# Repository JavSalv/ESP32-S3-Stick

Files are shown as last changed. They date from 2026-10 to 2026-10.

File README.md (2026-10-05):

# ESP32-S3 Stick

> Breadboard-friendly ESP32-S3 module with onboard RTC, LiPo battery charger, and USB-C — designed for low-power and deep-sleep applications.

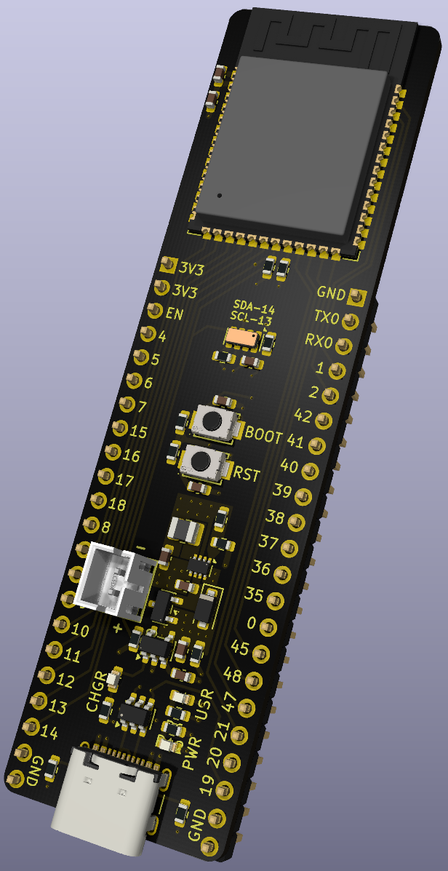
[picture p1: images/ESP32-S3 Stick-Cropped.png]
Board render


---

## Overview

The ESP32-S3 Stick is a compact development module built around the **ESP32-S3-WROOM-1** that fits standard 830-point breadboards leaving room on both sides of the module.
It combines a complete power path (USB-C input, LiPo charging, and a synchronous buck converter) with an ultra-low-power RTC clock, making it well suited for prototyping battery-operated IoT nodes, data loggers, and any application that relies on deep sleep.

---

## Features

### Microcontroller
- **ESP32-S3-WROOM-1-N16R2**: Dual-core Xtensa LX7 @ up to 240 MHz, 16 MB Flash, 2 MB PSRAM
- All GPIOs broken out to the standard 22-pin headers.

### Power
- **USB-C input** (USB 2.0, 16-pin receptacle) with correct CC pull-downs for UFP/sink detection
- **MCP73831** single-cell LiPo/Li-Ion charger with 100 mA charge current (configurable via R_PROG)
- **TPS629210** synchronous buck converter for 3.3V output up to 1A.
- **P-channel MOSFET load-sharing** (DMP2045U-7) seamless switchover between USB and battery with low dropout penalty.
- **USBLC6-2SC6** TVS diode array for USB ESD protection.

### RTC
- **RV-3028-C7** — ultra-low-power RTC (40 nA), ±1 ppm accuracy, I²C interface on IO13 (SCL) / IO14 (SDA)

### Connectivity & I/O
- **USB-C** - USB 2.0 FS data lines connected directly to ESP32-S3 USB transceiver (USB_D+ / USB_D−)
- **UART0** (TXD0 / RXD0) broken out for programming and debug
- **2 × 22-pin headers** 2.54 mm pitch, breadboard-compatible

### User Interface
- **RST button**: Reset the controller
- **BOOT button**: Enters download mode when held during reset
- **3 × status LEDs**: Charge status, power status and one user LED connected to GPIO48

---

## Pin Map

The Pin Map is similar to other ESP32-S3 modules like the ESP32-S3-DevKitC-1 or cheaper AliExpress clones.

ESP32-S3-DevKitC-1 Pinout

> **Note:** IO0 is the BOOT strapping pin — avoid driving it LOW at power-on unless entering download mode. IO45 and IO46 are also strapping pins; check the ESP32-S3 datasheet before using them as outputs.

### LiPo Battery

Connect a single-cell LiPo or Li-Ion battery (3.7 V nominal) to the battery connector (JST PH 2-pin 2mm pitch connector). The MCP73831 charges the battery at 100mA.

## License

Hardware design files are open source. See [LICENSE](LICENSE) for details.

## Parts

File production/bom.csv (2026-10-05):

Designator | Footprint | Quantity | Value | LCSC Part #
BT1 | CONN-TH_B2B-PH-K-S | 1 | JST Battery connector | C131337
C1, C9 | 0603 | 2 | 22uF
C2, C3, C4, C7 | 0603 | 4 | 0.1uF
C5, C6, C8 | 0603 | 3 | 4.7uF
D1, D2, D3 | 0603 | 3 | LED_R
D4 | D_SOD-123F | 1 | SS24
J1 | USB_C_Receptacle_GCT_USB4105-xx-A_16P_TopMnt_Horizontal | 1 | USB_C_Receptacle_USB2.0_16P
J2, J3 | PinHeader_1x22_P2.54mm_Vertical | 2 | Header 22pin
L1 | 1008 | 1 | 2.2uH
Q1 | SOT-23 | 1 | DMP2045U-7
R1, R10, R11, R4, R7, R8, R9 | 0603 | 7 | 10K
R12, R2, R3, R5, R6 | 0603 | 5 | 5.1K
R13 | 0603 | 1 | 100K
R14 | 0603 | 1 | 619K/0.1%
R15 | 0603 | 1 | 137K/0.1%
SW1, SW2 | SW-SMD_L3.9-W3.0-P4.45 | 2 | Tactile SW | C115357
U1 | ESP32-S3-WROOM-1 | 1 | ESP32-S3-WROOM-1
U2 | SOT-23-6 | 1 | USBLC6-2SC6
U3 | SOT-23-5 | 1 | MCP73831-2-OT
U4 | MicroCrystal_C7_SON-8_1.5x3.2mm_P0.9mm | 1 | RV-3028-C7
U5 | SOT-583-8 | 1 | TPS629210

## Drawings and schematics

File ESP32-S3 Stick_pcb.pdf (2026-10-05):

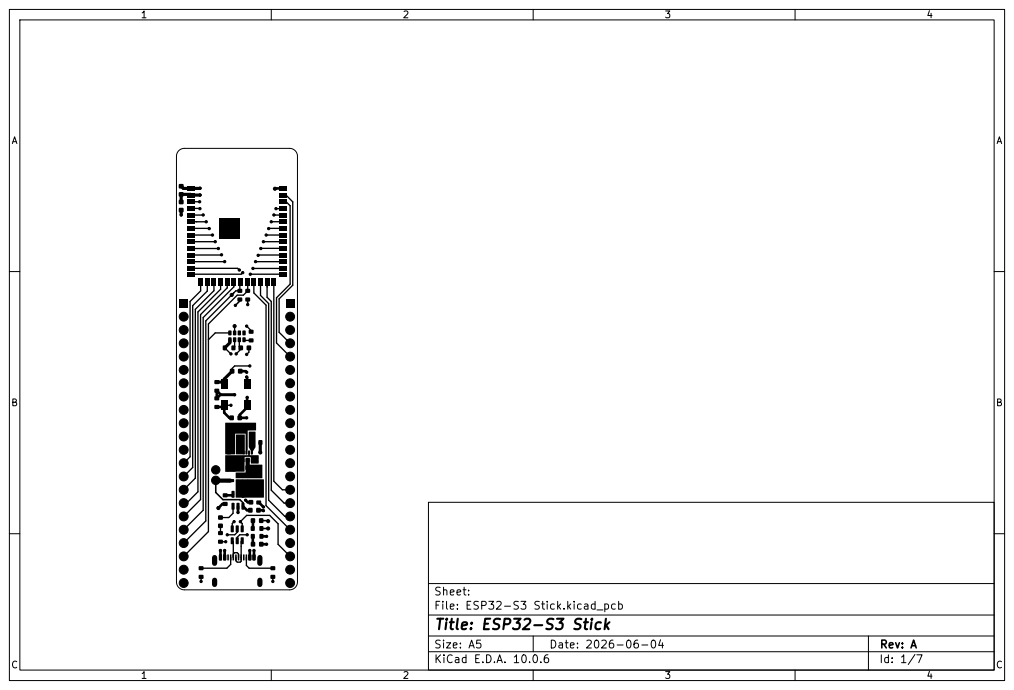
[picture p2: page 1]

Size: A5 | Rev: A | C Date: 2026-06-04
KiCad E.D.A. 10.0.6 | Id: 1/7

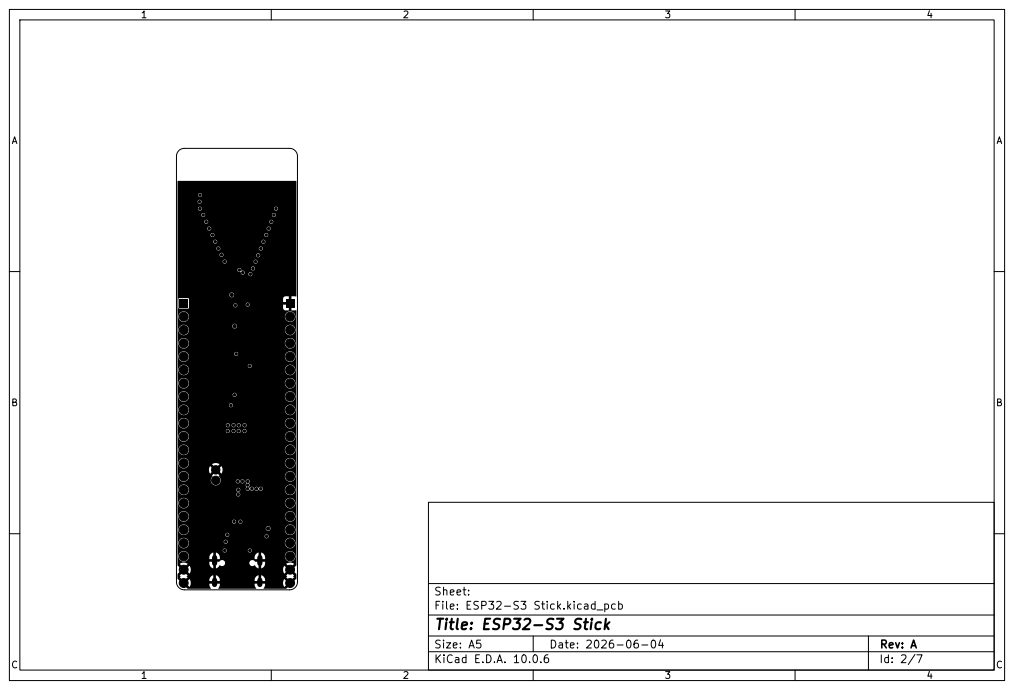
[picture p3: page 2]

Size: A5 | Rev: A | C Date: 2026-06-04
KiCad E.D.A. 10.0.6 | Id: 2/7

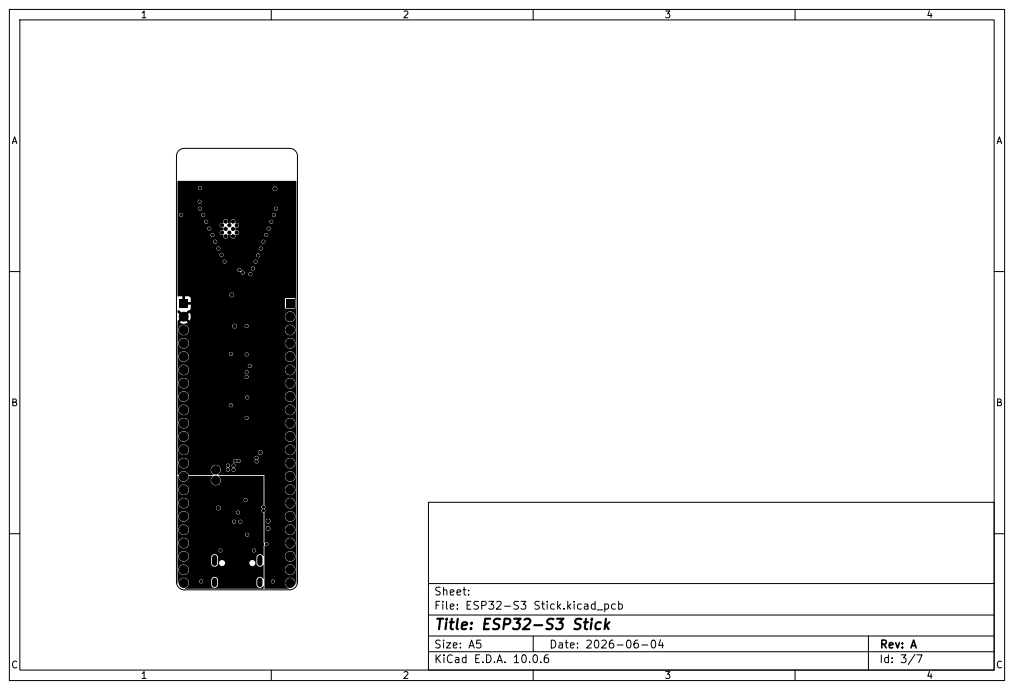
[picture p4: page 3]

Size: A5 | Rev: A | C Date: 2026-06-04
KiCad E.D.A. 10.0.6 | Id: 3/7

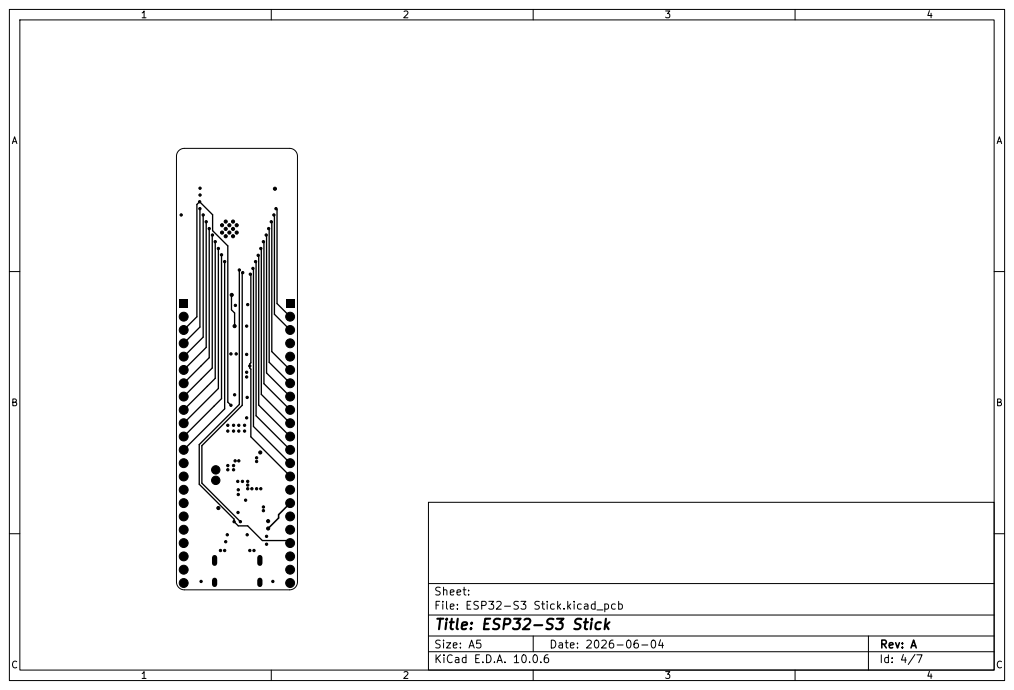
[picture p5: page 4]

Size: A5 | Rev: A | C Date: 2026-06-04
KiCad E.D.A. 10.0.6 | Id: 4/7

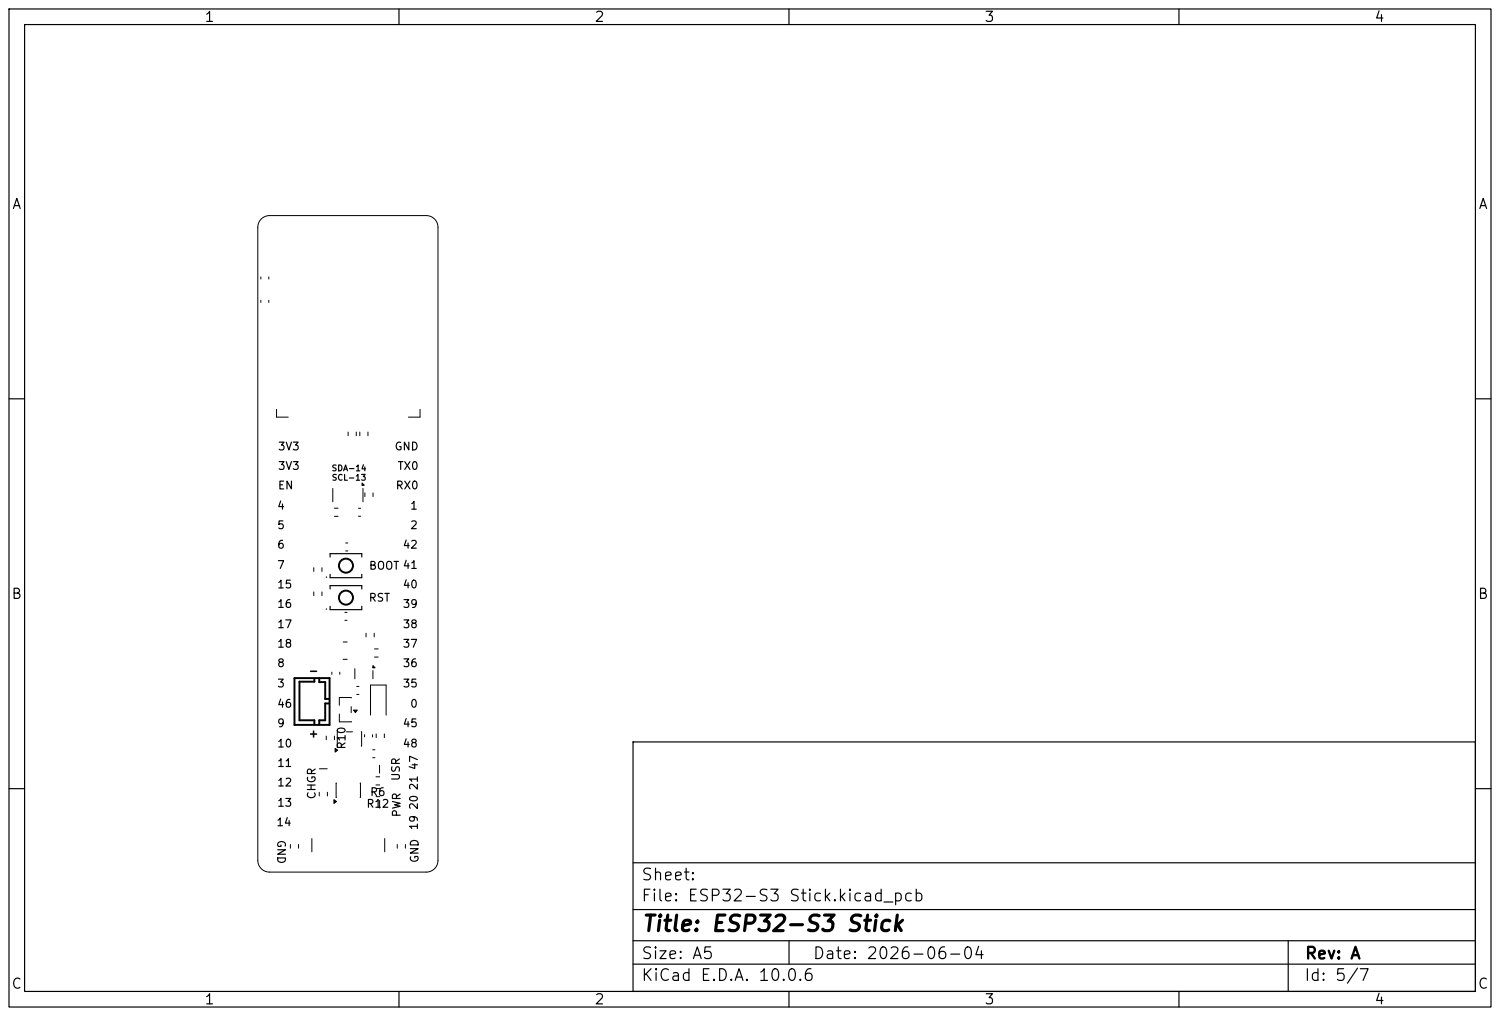
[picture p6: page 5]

Size: A5 | Rev: A | C Date: 2026-06-04
KiCad E.D.A. 10.0.6 | Id: 5/7

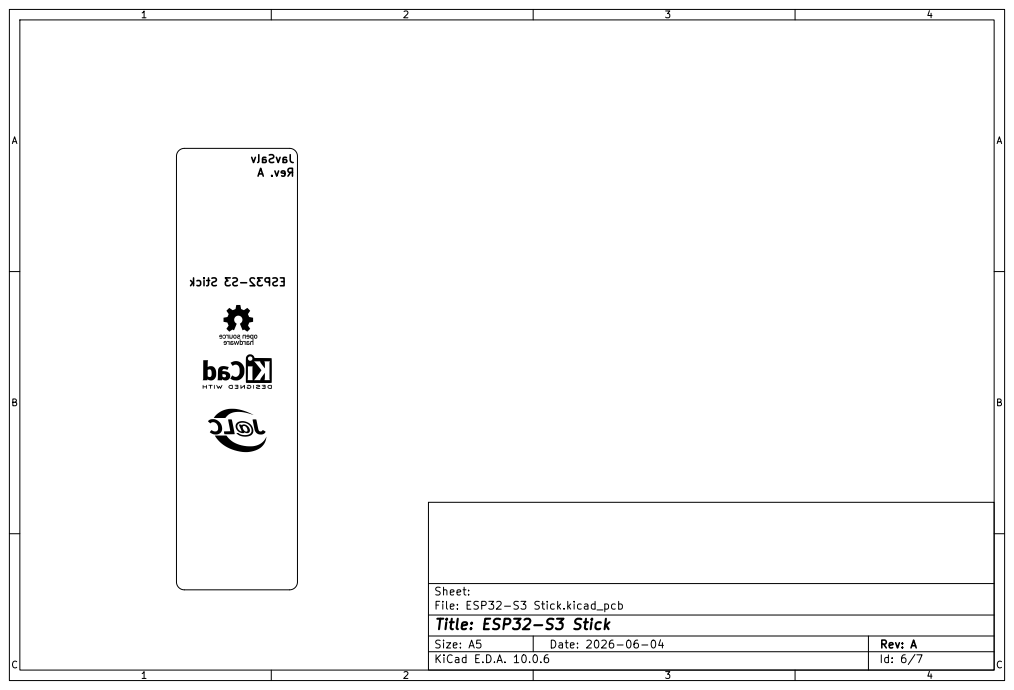
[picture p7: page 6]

Size: A5 | Rev: A | C Date: 2026-06-04
KiCad E.D.A. 10.0.6 | Id: 6/7

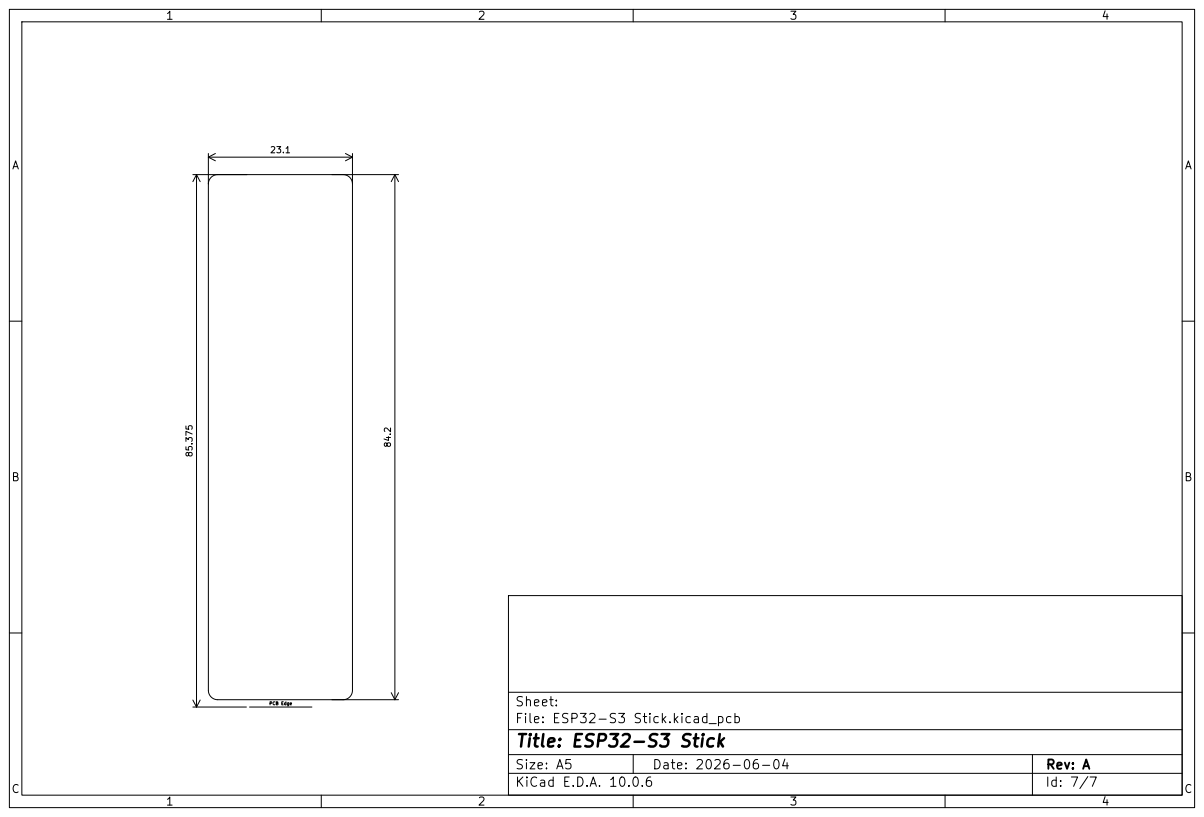
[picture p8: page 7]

Size: A5 | Rev: A | C Date: 2026-06-04
KiCad E.D.A. 10.0.6 | Id: 7/7

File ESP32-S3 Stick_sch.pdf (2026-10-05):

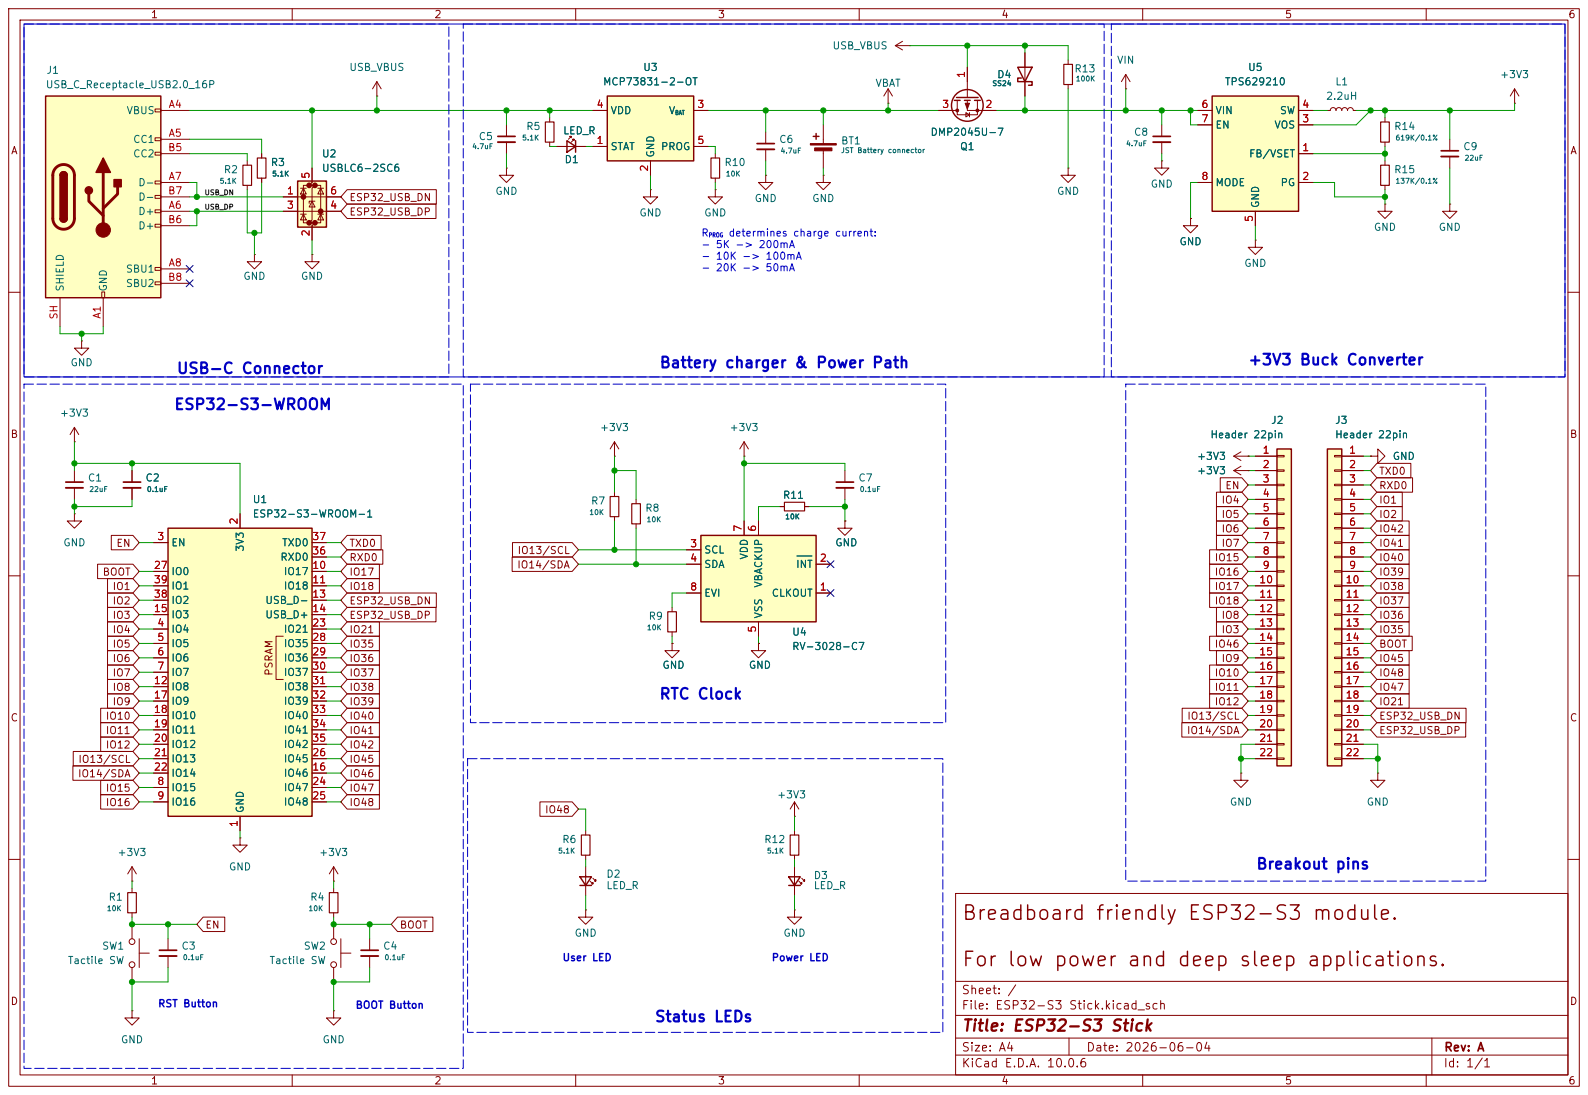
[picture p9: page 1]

VIN 6
RPROG determines charge current: - 5K -> 200mA - 10K -> 100mA - 20K -> 50mA Status LEDs

For low power and deep sleep applications.

Size: A4 | Rev: A
KiCad E.D.A. 10.0.6 | Id: 1/1

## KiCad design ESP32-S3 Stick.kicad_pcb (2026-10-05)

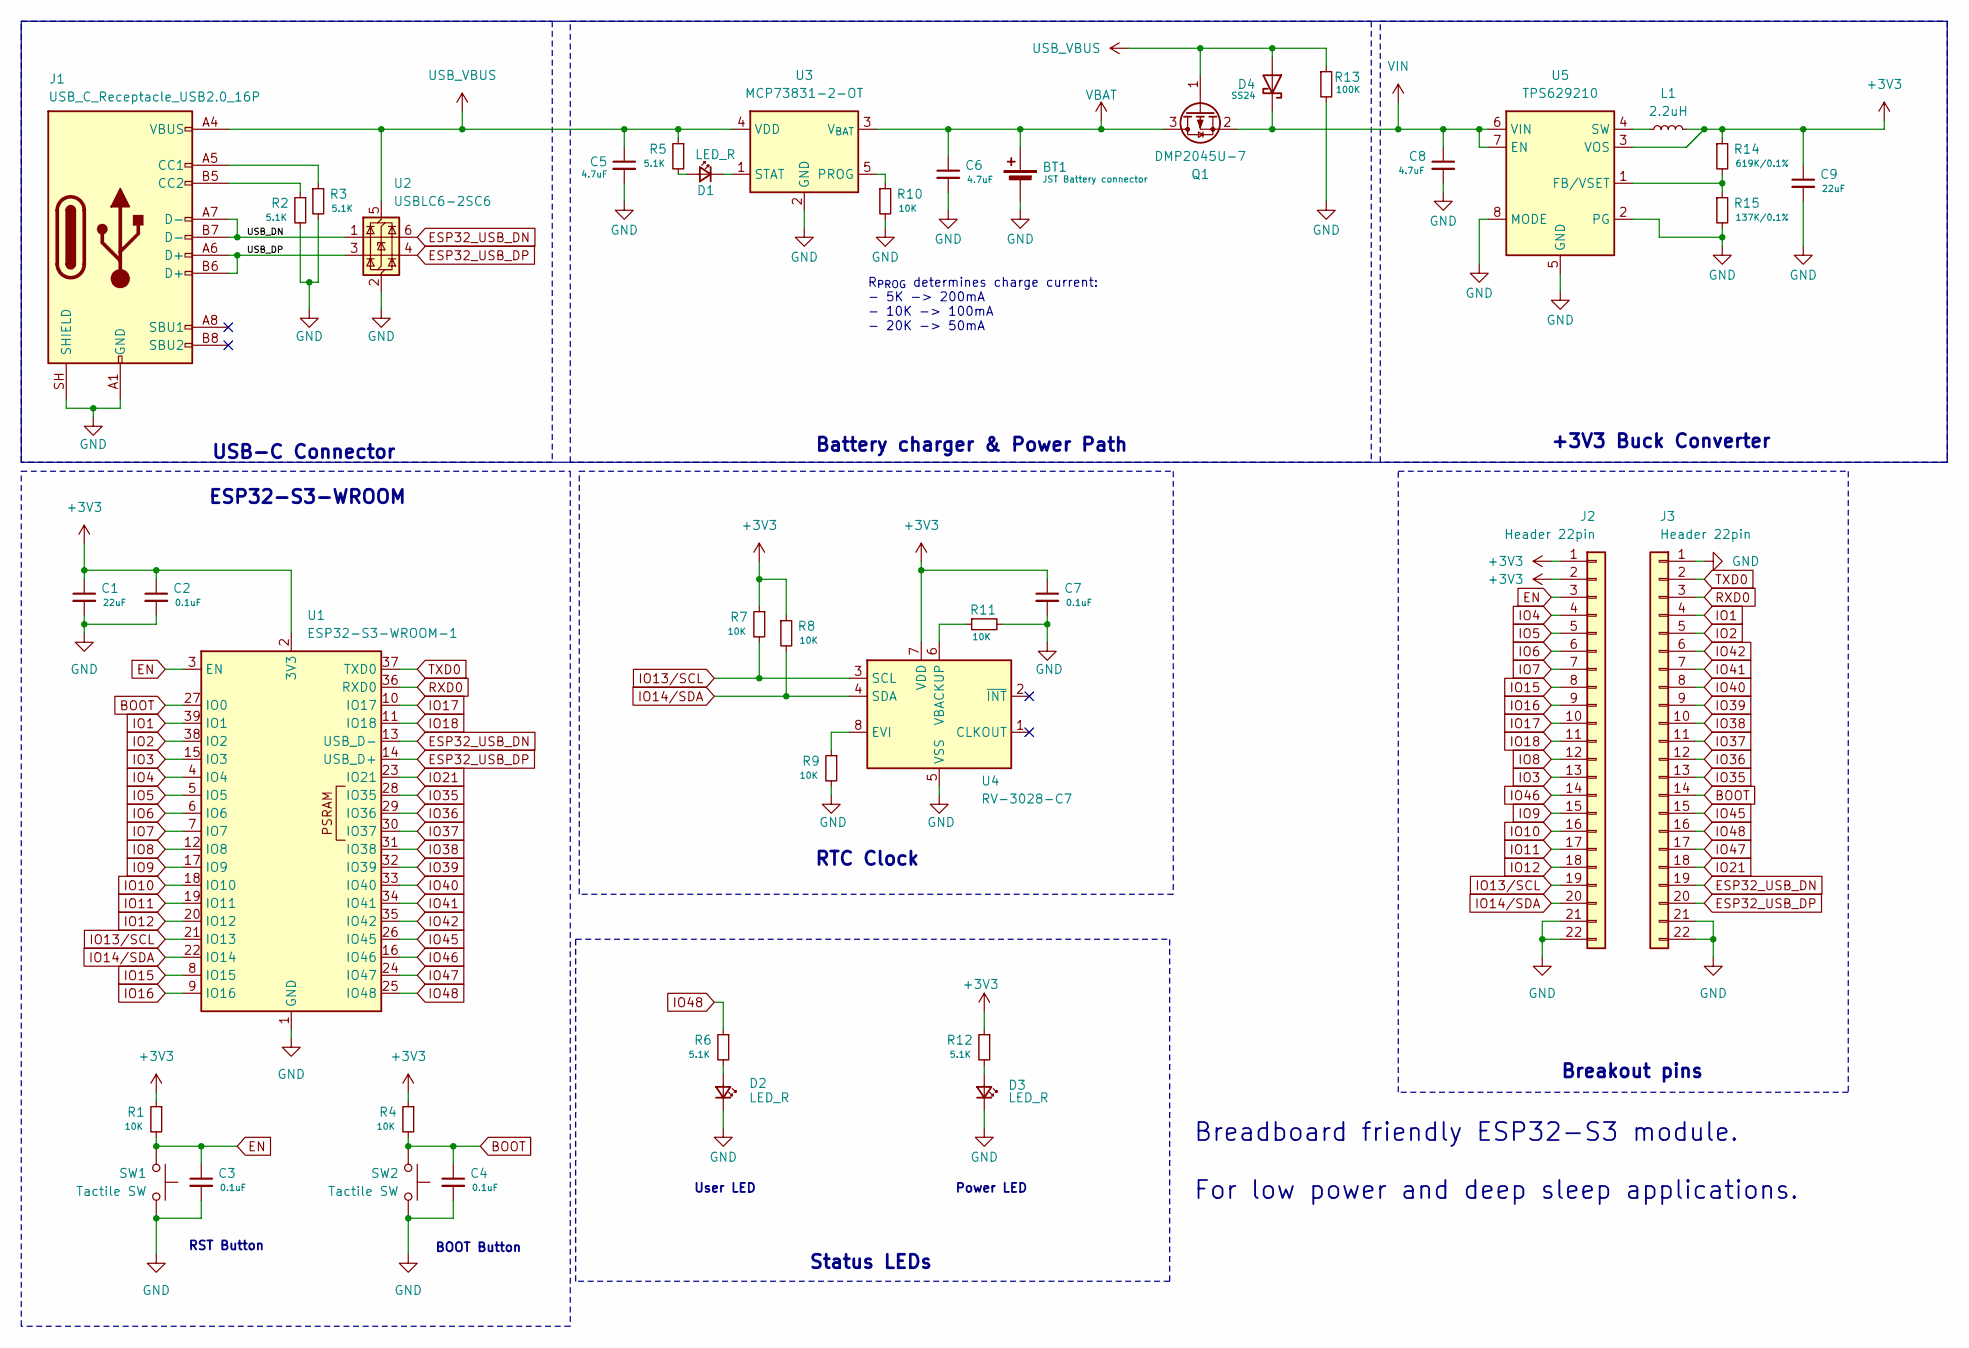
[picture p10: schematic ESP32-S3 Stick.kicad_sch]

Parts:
BT1: JST Battery connector; CONN-TH_B2B-PH-K-S; digikey# 455-1704-ND
C1, C9: 22uF; C_0603_1608Metric; digikey# 1276-1274-1-ND
C2, C3, C4, C7: 0.1uF; C_0603_1608Metric; digikey# 1276-1000-1-ND
C5, C6, C8: 4.7uF; C_0603_1608Metric; digikey# 1276-1900-1-ND
D1, D2, D3: LED_R; LED_0603_1608Metric; digikey# 160-1830-1-ND
D4: SS24; D_SOD-123F; digikey# 1801-SS24LWCT-ND
J1: USB_C_Receptacle_USB2.0_16P; USB_C_Receptacle_GCT_USB4105-xx-A_16P_TopMnt_Horizontal; digikey# 2073-USB4215-03-ACT-ND
J2, J3: Header 22pin; PinHeader_1x22_P2.54mm_Vertical; lcsc# C41375941
L1: 2.2uH; L_1008_2520Metric; digikey# 490-DFE252012PD-2R2M=P2CT-ND
Q1: DMP2045U-7; SOT-23; lcsc# C459541
R1, R4, R7, R8, R9, R10, R11: 10K; R_0603_1608Metric; digikey# YAG1236CT-ND
R2, R3, R5, R6, R12: 5.1K; R_0603_1608Metric; digikey# YAG1696CT-ND
R13: 100K; R_0603_1608Metric; digikey# 311-100KGRCT-ND
R14: 619K/0.1%; R_0603_1608Metric; digikey# MCT0603MD6193BP500
R15: 137K/0.1%; R_0603_1608Metric; digikey# ERA-3AEB1373V
SW1, SW2: Tactile SW; SW-SMD_L3.9-W3.0-P4.45; digikey# 4809-SKRKAEE020CT-ND
U1: ESP32-S3-WROOM-1; digikey# 5407-ESP32-S3-WROOM-1-N16R2CT-ND
U2: USBLC6-2SC6; SOT-23-6; digikey# 5399-USBLC6-2SC6CT-ND
U3: MCP73831-2-OT; SOT-23-5; digikey# MCP73831T-2ACI/OTCT-ND
U4: RV-3028-C7; MicroCrystal_C7_SON-8_1.5x3.2mm_P0.9mm; lcsc# C3019759
U5: TPS629210; SOT-583-8; digikey# 296-TPS629210DRLRCT-ND

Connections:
+3V3: C1.1, C2.1, C7.1, C9.1, J2.1, J2.2, L1.2, R1.1, R4.1, R7.1, R8.1, R12.1, R14.1, U1.2 (3V3), U4.7 (VDD), U5.3 (VOS)
/USB_DN: J1.A7 (D-), J1.B7 (D-), U2.1 (I/O1)
/USB_DP: J1.A6 (D+), J1.B6 (D+), U2.3 (I/O2)
BOOT: C4.1, J3.14, R4.2, SW2.2, U1.27 (IO0)
EN: C3.1, J2.3, R1.2, SW1.2, U1.3 (EN)
ESP32_USB_DN: J3.19, U1.13 (USB_D-), U2.6 (I/O1)
ESP32_USB_DP: J3.20, U1.14 (USB_D+), U2.4 (I/O2)
GND: BT1.2 (-), C1.2, C2.2, C3.2, C4.2, C5.2, C6.2, C7.2, C8.2, C9.2, D2.1 (K), D3.1 (K), J1.A1 (GND), J1.A12 (GND), J1.B1 (GND), J1.B12 (GND), J1.SH (SHIELD), J2.21, J2.22, J3.1, J3.21, J3.22, R2.2, R3.2, R9.2, R10.2, R11.2, R13.2, R15.2, SW1.1, SW2.1, U1.1 (GND), U1.40 (GND), U1.41 (GND), U2.2 (GND), U3.2 (GND), U4.5 (VSS), U5.2 (PG), U5.5 (GND), U5.8 (MODE)
IO1: J3.4, U1.39 (IO1)
IO2: J3.5, U1.38 (IO2)
IO3: J2.13, U1.15 (IO3)
IO4: J2.4, U1.4 (IO4)
IO5: J2.5, U1.5 (IO5)
IO6: J2.6, U1.6 (IO6)
IO7: J2.7, U1.7 (IO7)
IO8: J2.12, U1.12 (IO8)
IO9: J2.15, U1.17 (IO9)
IO10: J2.16, U1.18 (IO10)
IO11: J2.17, U1.19 (IO11)
IO12: J2.18, U1.20 (IO12)
IO13/SCL: J2.19, R7.2, U1.21 (IO13), U4.3 (SCL)
IO14/SDA: J2.20, R8.2, U1.22 (IO14), U4.4 (SDA)
IO15: J2.8, U1.8 (IO15)
IO16: J2.9, U1.9 (IO16)
IO17: J2.10, U1.10 (IO17)
IO18: J2.11, U1.11 (IO18)
IO21: J3.18, U1.23 (IO21)
IO35: J3.13, U1.28 (IO35)
IO36: J3.12, U1.29 (IO36)
IO37: J3.11, U1.30 (IO37)
IO38: J3.10, U1.31 (IO38)
IO39: J3.9, U1.32 (IO39)
IO40: J3.8, U1.33 (IO40)
IO41: J3.7, U1.34 (IO41)
IO42: J3.6, U1.35 (IO42)
IO45: J3.15, U1.26 (IO45)
IO46: J2.14, U1.16 (IO46)
IO47: J3.17, U1.24 (IO47)
IO48: J3.16, R6.1, U1.25 (IO48)
unnamed: D1.2 (A), R5.2
unnamed: D1.1 (K), U3.1 (STAT)
unnamed: D2.2 (A), R6.2
unnamed: D3.2 (A), R12.2
unnamed: J1.A5 (CC1), R3.1
unnamed: J1.B5 (CC2), R2.1
unnamed: R10.1, U3.5 (PROG)
unnamed: R9.1, U4.8 (EVI)
unnamed: R11.1, U4.6 (VBACKUP)
unnamed: R14.2, R15.1, U5.1 (FB/VSET)
unnamed: L1.1, U5.4 (SW)
RXD0: J3.3, U1.36 (RXD0)
TXD0: J3.2, U1.37 (TXD0)
USB_VBUS: C5.1, D4.2 (A), J1.A4 (VBUS), J1.A9 (VBUS), J1.B4 (VBUS), J1.B9 (VBUS), Q1.1 (G), R5.1, R13.1, U2.5 (VBUS), U3.4 (VDD)
VBAT: BT1.1 (+), C6.1, Q1.3 (D), U3.3 (V_{BAT})
VIN: C8.1, D4.1 (K), Q1.2 (S), U5.6 (VIN), U5.7 (EN)

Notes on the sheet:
BOOT Button
RTC Clock
User LED
Status LEDs
R_{PROG} determines charge current: - 5K -> 200mA - 10K -> 100mA - 20K -> 50mA
ESP32-S3-WROOM
RST Button
Breakout pins
Breadboard friendly ESP32-S3 module. For low power and deep sleep applications.
Power LED
USB-C Connector
+3V3 Buck Converter
Battery charger & Power Path

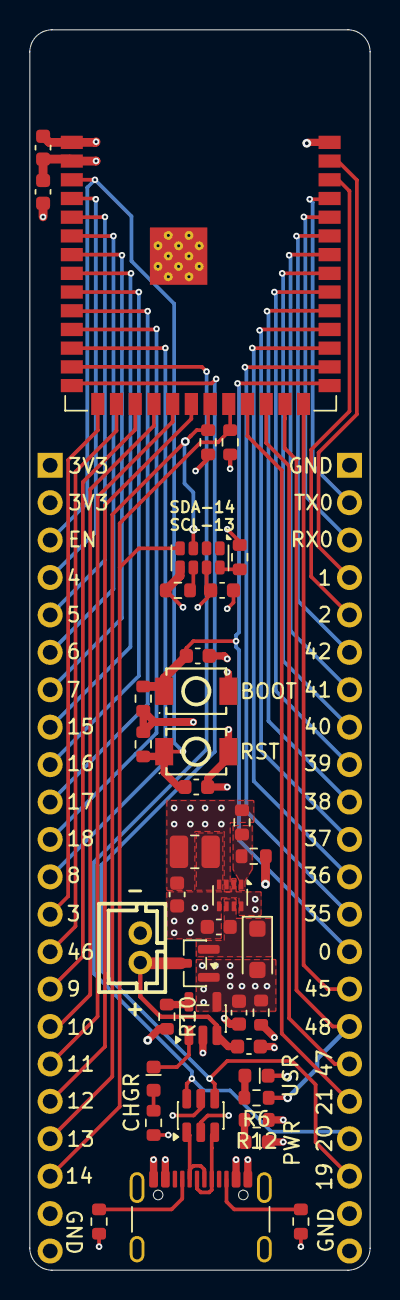
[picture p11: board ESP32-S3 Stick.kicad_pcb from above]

Board: 4 copper layers, 23.1 x 84.2 mm, 41 parts (0 on the bottom side), 55 nets.

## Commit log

2026-06-23 Add production folder
    [ESP32-S3 Stick BOM.csv, designators.csv, positions.csv]
2026-10-05 Fixed Broken Symbols
    [ESP32-S3 Stick.kicad_pcb, ESP32-S3 Stick.kicad_sch]
2026-10-05 Fixed and remapped symbols
    [ESP32-S3 Stick.kicad_pcb, ESP32-S3 Stick.kicad_sch]
2026-10-05 Fix Silkscreen and re-create fab. files
    [ESP32-S3 Stick BOM.csv, ESP32-S3 Stick.kicad_pcb, bom.csv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]
